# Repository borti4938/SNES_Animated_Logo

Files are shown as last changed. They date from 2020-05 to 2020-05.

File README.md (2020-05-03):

### Animated Logo for the SNES
---

This is an earlier project. This project is not under development anymore. Documentation is rather simple or simply not present.

Please don't write me for any support. Please reach out to community forums and use the knowledge and experiences there.

Best Regards, Peter

---

### From Original README

##### Installation

The PCB is designed to be assembled to the extension port of the ‘normal’ SNES.
/Rst is a combination of a pad and a jumper, which can be used as follows:
– connect the pad with a wire to CIC pad 10 (animation is repeated on a reset using reset button and the IGR (PIC-microcontroller code)
– close jumper: animation is repeated on every reset (I do not like this, e.g., because the sd2snes performs a reset on startup and the animation is started a second time while the initial animation is running)
– neither connect the wire or the close the jumper: animation is just played once

##### Others:

- Software: http://circuit-board.de/forum/index.php/Thread/7573-Super-Nintendo-Beleuchtetes-animiertes-Logo/ (can now be accessed here, too)
- Fuse Bits for the ATTiny45: lfuse: 0xe2, hfuse:w:0xdf
- The given resistor values for the LEDs (2x 180Ohm (yellow, red) and 2x 120Ohm (green, blue)) are just examples. You may adjust these values according to your needs :)
- LEDs are in 0805 or P-LCC-2 package.

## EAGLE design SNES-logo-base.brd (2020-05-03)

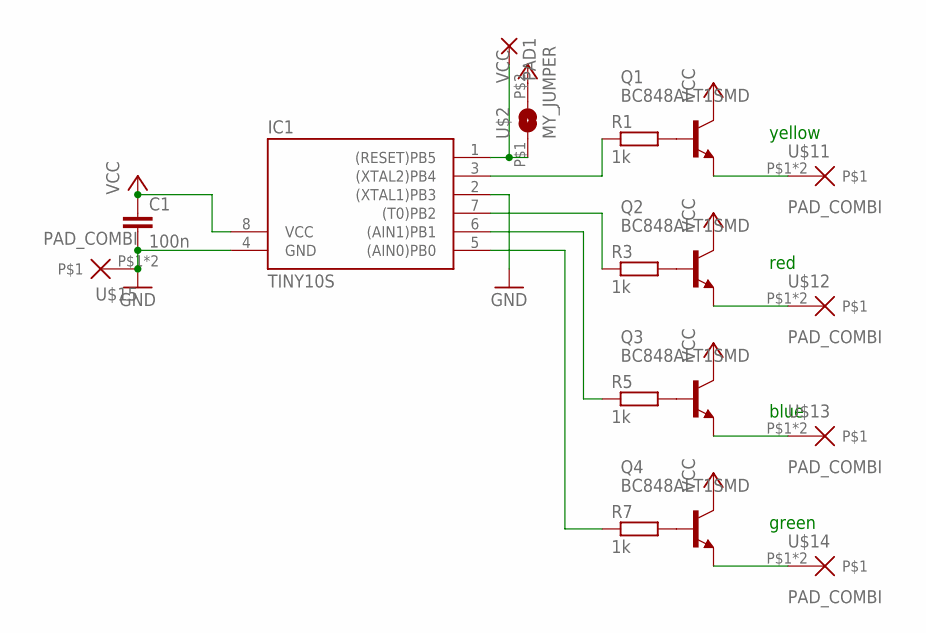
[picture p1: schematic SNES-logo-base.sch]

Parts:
C1: 100n; Z0805
IC1: TINY10S; SOIC8
PAD1: SMD2; SMD1,27-2,54
Q1, Q2, Q3, Q4: BC848ALT1SMD; SOT23
R1, R3, R5, R7: 1k; Z0805
U$2: MY_JUMPER; MYJUMP
U$11, U$12, U$13, U$14, U$15: PAD_COMBI

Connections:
GND: C1.2, IC1.2 ((XTAL1)PB3), IC1.4 (GND), U$15.P$1, U$15.P$2
unnamed: Q2.2 (E), U$12.P$1, U$12.P$2
unnamed: IC1.1 ((RESET)PB5), PAD1.1, U$2.P$1 (1)
unnamed: Q3.2 (E), U$13.P$1, U$13.P$2
unnamed: Q1.1 (B), R1.2
unnamed: Q2.1 (B), R3.2
unnamed: Q3.1 (B), R5.2
unnamed: Q4.1 (B), R7.2
unnamed: Q4.2 (E), U$14.P$1, U$14.P$2
unnamed: Q1.2 (E), U$11.P$1, U$11.P$2
unnamed: IC1.3 ((XTAL2)PB4), R1.1
unnamed: IC1.7 ((T0)PB2), R3.1
unnamed: IC1.6 ((AIN1)PB1), R5.1
unnamed: IC1.5 ((AIN0)PB0), R7.1
VCC: C1.1, IC1.8 (VCC), Q1.3 (C), Q2.3 (C), Q3.3 (C), Q4.3 (C), U$2.P$2 (2)

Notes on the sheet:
yellow
red
blue
green

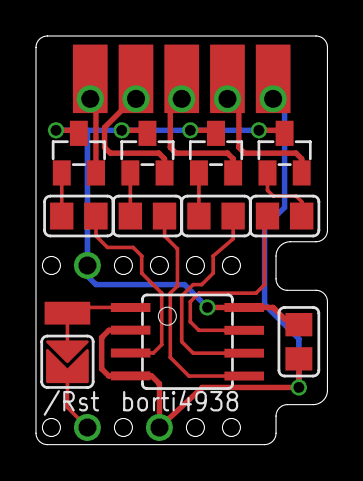
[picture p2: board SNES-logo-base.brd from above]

Board: 2 copper layers, 16.2 x 22.7 mm, 17 parts (0 on the bottom side), 15 nets.

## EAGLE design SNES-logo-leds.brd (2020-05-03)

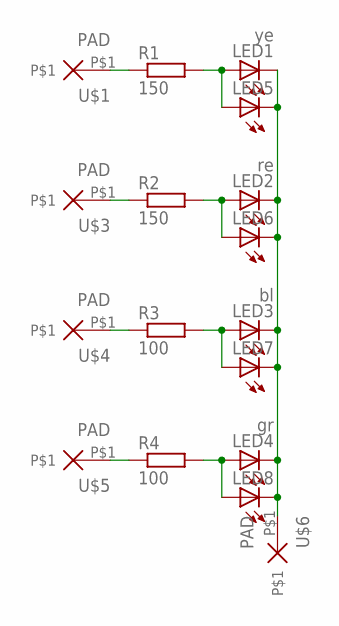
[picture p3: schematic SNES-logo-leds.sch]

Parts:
LED1: ye; SML0805
LED2: re; SML0805
LED3: bl; SML0805
LED4: gr; SML0805
LED5, LED6, LED7, LED8: LEDP-LCC-2; P-LCC-2
R1, R2: 150; Z0805
R3, R4: 100; Z0805
U$1, U$3, U$4, U$5, U$6: PAD

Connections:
unnamed: LED1.C, LED2.C, LED3.C, LED4.C, LED5.C, LED6.C, LED7.C, LED8.C, U$6.P$1
unnamed: R2.1, U$3.P$1
unnamed: LED1.A, LED5.A, R1.2
unnamed: R1.1, U$1.P$1
unnamed: R3.1, U$4.P$1
unnamed: R4.1, U$5.P$1
unnamed: LED2.A, LED6.A, R2.2
unnamed: LED3.A, LED7.A, R3.2
unnamed: LED4.A, LED8.A, R4.2

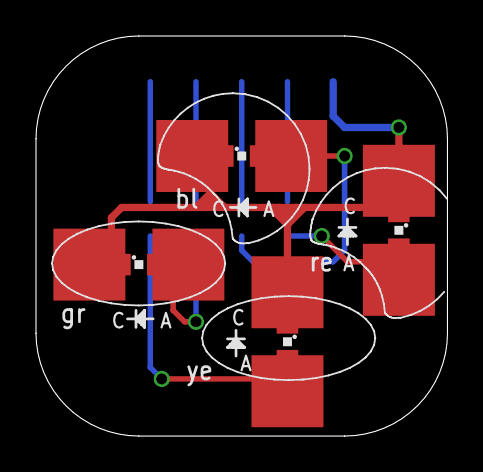
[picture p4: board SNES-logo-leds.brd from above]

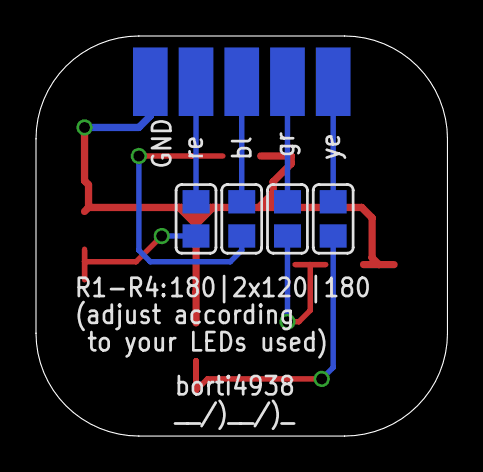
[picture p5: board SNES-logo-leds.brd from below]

Board: 2 copper layers, 22.9 x 22.2 mm, 17 parts (9 on the bottom side), 9 nets.

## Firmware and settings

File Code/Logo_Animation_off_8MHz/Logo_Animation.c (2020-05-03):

/*Logo-Beleuchtung SNES fuer scorp angepasst
 (c) jensma, jensma.de, 2012 
 ported to atmel studio 2013 sanni
 */

#include <avr/io.h>
#define F_CPU 8000000UL
// #define F_CPU 1000000UL
#include <avr/sleep.h>
#include <util/delay.h>

int led[4]={0,1,2,4}; // Pins mit LEDs
int count = 0;
double geschw = 1;
int verz = 10;
int modus = 0;
int breakout = 1;

uint8_t LOW = 0;
uint8_t HIGH = 1;

void delayMicroseconds(uint16_t us)
{
  while(us--) {
    _delay_us(1);
  }
}  


void digitalWrite(uint8_t pin, uint8_t val)
{
  if (val == LOW) {
    PORTB &= ~(1<<pin);
  } 
  else {
    PORTB |= (1<<pin);
  }
}

//Software PWM on Attiny85 von Ernst Christensen 16.okt. 2011, angepasst von jensma
void pwm(int freq,int spin)
{
  digitalWrite(spin,HIGH);
  delayMicroseconds(1*freq);
  digitalWrite(spin,LOW);
  delayMicroseconds(1*(255-freq));
}

int main(void)
{   
  //set outputs PortB
  DDRB |= (1<<0);
  DDRB |= (1<<1);
  DDRB |= (1<<2);
  DDRB |= (1<<4);
  

  while(1){

    for (count = 0; count < 4; count++)
    {
      for (int i = 1; i < 190; i+=1)//LED aufhellen
      {
        pwm(i,led[count]);
        delayMicroseconds(geschw);
      }

      for (int i = 1; i < 190; i+=1)//Und wieder abdunkeln
      {
        pwm(191-i,led[count]);
        delayMicroseconds(2*geschw);
      }

      verz++;

      if (verz > 16) {
        geschw *= 1.5;
      }//Das Aufhellen wird verlangsamt
      if (verz > 32) // In der letzten Phase leuchten alle LEDs noch mal auf
      {
        geschw = 1; //Ich recycle die Variablen mal, das schont den schmalen Platz
        verz = 0;
        modus = 0;
		breakout = 0;
        do {
          verz++; //Tick-Value



          if (verz > 3) {
            if (modus == 0) {
              geschw+=2;
            }
            else{
              geschw-=2;
            }
            verz = 0;

            if (geschw >= 250) {
              modus = 1;
            }

          }

          for (count = 0; count < 4; count++){
			pwm(geschw,led[count]);
          }

		  // if (geschw <= 50 && modus == 1)
          if (geschw == 1 && modus == 1)
          {
			breakout=1;
		  }

        }
        while (breakout==0); 
		while(1)
		{
			for (count = 0; count < 4; count++){
			//	pwm(50,led[count]);
			    digitalWrite(led[count],LOW);
			}
			set_sleep_mode(SLEEP_MODE_PWR_DOWN);
			sleep_mode();                   // in den Schlafmodus wechseln
		}
	  }
	}
  }
}
